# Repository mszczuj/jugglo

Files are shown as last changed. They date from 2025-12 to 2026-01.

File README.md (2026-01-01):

# Jugglo

This is a hobby IMU-based juggling ball project that streams inertial data over IP/UDP to a computer for visualization and sonification. 

Wi-Fi credentials live in `src/wifi_secret.h` (see below).

### 3d files 

3d files in stl (ball and electronics enclosure) for printing are in folder 3dfiles and were generated using cadquery

### Hardware

- Board: ESP32-C6 DevKitC-1
- IMU: BMI160 (I2C address 0x69)
- Wiring: SCL → GPIO20, SDA → GPIO19 (internal pull-ups enabled)

### Receiving data on the host
- Ensure the host machine is reachable at `MASTER_HOST` on `MASTER_PORT`.
- View raw sensor data and orientation filter output with:
```bash
> python read.py
14873,584,2,3996,-0.98681640625,-0.1142578125,0.056640625,0.244140625,0.0,0.1220703125,0,0,1767274563.513852
14873,584,2,3996,-0.986328125,-0.11376953125,0.05810546875,0.244140625,-0.06103515625,0.06103515625,1,0,1767274563.5138826
14873,584,2,3996,-0.98583984375,-0.11376953125,0.05908203125,0.244140625,-0.06103515625,0.06103515625,2,0,1767274563.5138955
...
```
Each row in console spam is csv formatted imu data with following columns:
```bash
timestamp_ms,device_sequence_number,sensor_id,battery_mv,accel_x,accel_y,accel_z,gyro_x,gyro_y,gyro_z,sequence_number,checksum_good,host_timestamp
```
acceleremter are in g and gyro in deg/s 

In order to see the basic visualisation see here: 
```bash 
> python read.py | python plot_raw_vis.py 
```

### Development 

The project is developed with PlatformIO on the Espressif platform (tested on Ubuntu; not yet on Windows).

#### TODO 
 - [ ] Easy Wi-Fi setup (without rebuilding the project / QR code or internal storage)
 - [ ] Recheck hardware design (external antenna and integrated IMU with microcontroller)
 - [ ] Pass the data to external VJ software

#### Configure secrets and target host

`src/wifi_secret.h` is git-ignored. Create it locally before building:
```c
#define WIFI_SSID "your-ssid"
#define WIFI_PASS "your-password"

// Host that receives UDP IMU packets
#define MASTER_HOST "host-or-ip"
#define MASTER_PORT 50555
```
M_H
> Note: `src/main.cpp` expects `MASTER_HOST`/`MASTER_PORT`; the default fallback defines `MASTER_*` but those macros are unused in the current code, so define the TCP_* values in your secret header.

## Build with PlatformIO
The repository also includes `platformio.ini`:
```bash
pio run -e esp32-c6-devkitc-1
pio run -e esp32-c6-devkitc-1 --target upload --upload-port /dev/ttyACM0
pio device monitor -e esp32-c6-devkitc-1
```

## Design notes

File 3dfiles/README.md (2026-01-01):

## 3d files for printing 

### TODO:
- [ ] redesign electronics enclosure  
make it more compact and put holder for button  
right now the antenna is put far away from battery to avoid communication problems (that may be possibly a overshoot)
- [ ] smaller ball 

### Ball

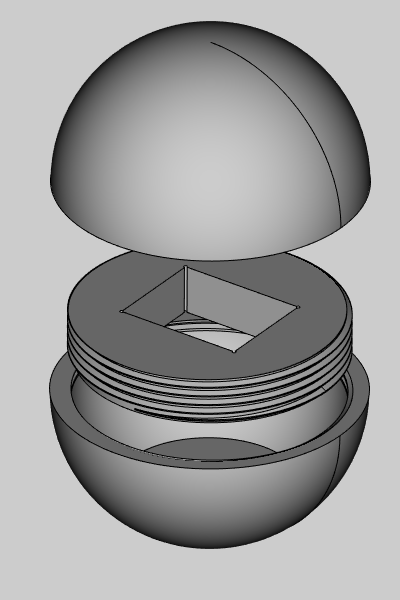
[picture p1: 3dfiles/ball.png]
Ball render


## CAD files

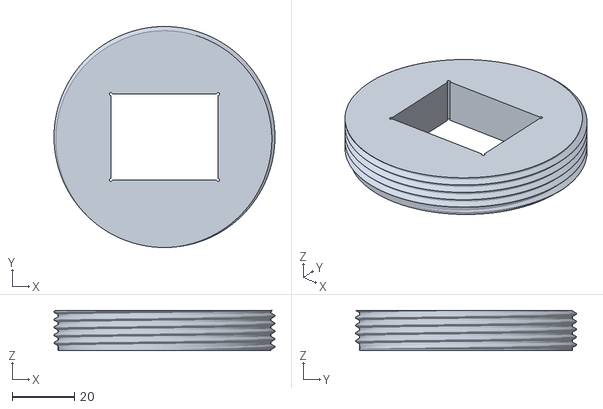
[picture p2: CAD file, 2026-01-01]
3dfiles/inner_thread.stl
71.2 x 71.2 x 13.0

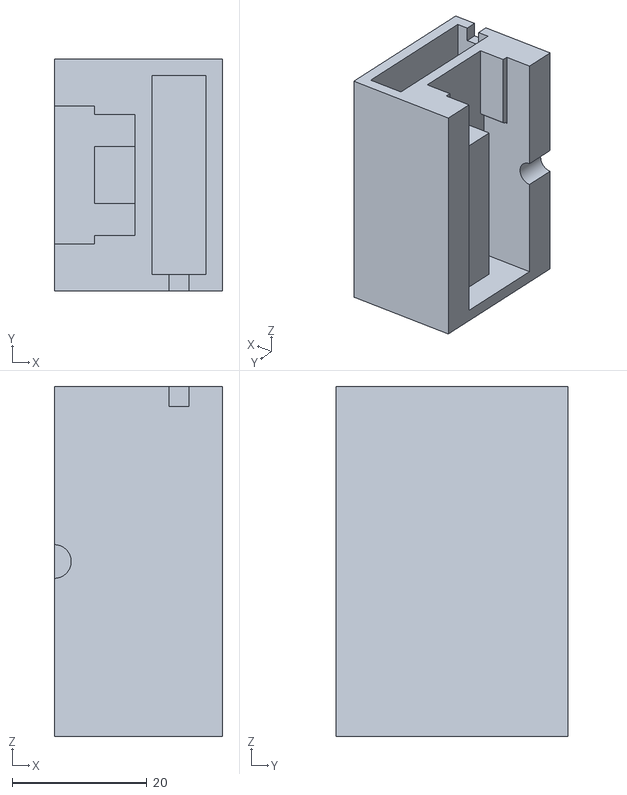
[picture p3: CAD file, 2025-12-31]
3dfiles/inner_box.stl
25.0 x 34.5 x 52.0

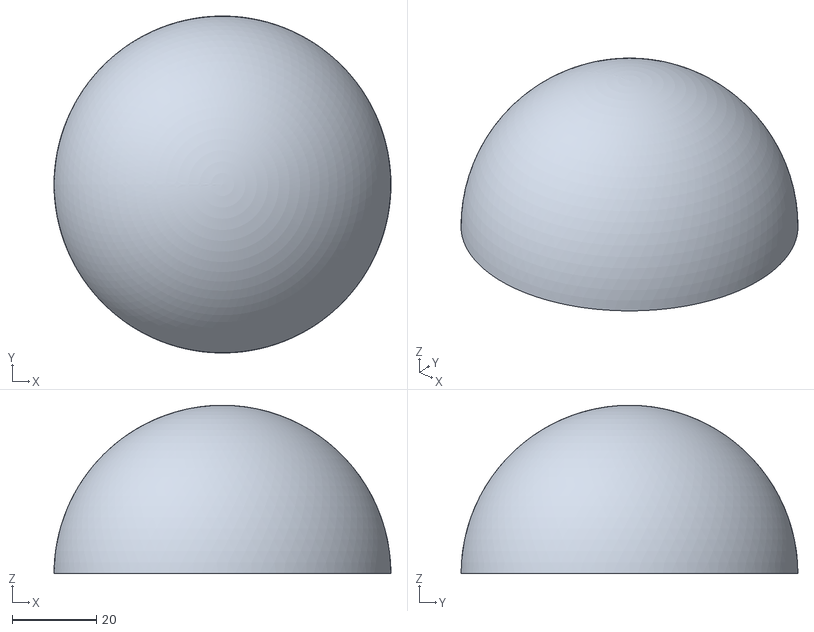
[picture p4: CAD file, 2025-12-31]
3dfiles/ball_lower.stl
80.0 x 80.0 x 40.0

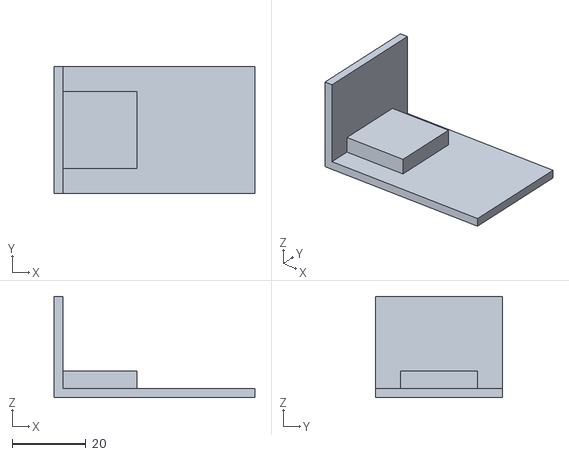
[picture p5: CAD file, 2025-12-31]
3dfiles/lid.stl
54.5 x 34.5 x 27.5

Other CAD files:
3dfiles/ball_upper.stl

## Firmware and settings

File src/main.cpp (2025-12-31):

#include "freertos/FreeRTOS.h"
#include "freertos/task.h"
#include "freertos/event_groups.h"
#include "driver/gpio.h"
#include "driver/i2c_master.h"
#include "esp_err.h"
#include "esp_log.h"
#include "esp_wifi.h"
#include "nvs_flash.h"
#include "esp_eap_client.h"
#include "esp_system.h"
#include "esp_netif.h"
#include "esp_event.h"
#include "driver/uart.h"
#include <netdb.h>
#include <cstdio>
#include <cerrno>
#include <cstring>
#include <sys/socket.h>
#include <unistd.h>

#include "battery.hpp"
#include "imu_bmi160.hpp"

#if __has_include("wifi_secret.h")
#include "wifi_secret.h"
#else
#warning "wifi_secret.h not found - using default WiFi credentials & master host/port"

#define WIFI_SSID "juglo_ap"
#define WIFI_PASS "jugl0mast4r"

#define MASTER_HOST "hostname.local"
#define MASTER_PORT 50555
#endif

#define I2C_SCL GPIO_NUM_20
#define I2C_SDA GPIO_NUM_19

#define I2C_FREQ_HZ 400000 // 400 kHz; higher speeds were flaky when WiFi traffic preempts I2C ISR
static i2c_master_bus_handle_t i2c_bus = nullptr;

#define DEFAULT_SCAN_LIST_SIZE 5

#define LED_GPIO GPIO_NUM_15   // ESP32-C6 DevKit LED

#define TAG "app"
#define BATTERY_ADC_UNIT     ADC_UNIT_1
#define BATTERY_ADC_CHANNEL  ADC_CHANNEL_0  // GPIO0 on ESP32-C6; change if your battery divider is on another pin
#define BATTERY_ADC_ATTEN    ADC_ATTEN_DB_11
#define BATTERY_DIVIDER_RATIO 2.0f          // scale ADC pin voltage back to battery voltage

static BatteryMonitor s_battery(BATTERY_ADC_UNIT, BATTERY_ADC_CHANNEL, BATTERY_ADC_ATTEN, BATTERY_DIVIDER_RATIO);

static void init_i2c(void)
{
    i2c_master_bus_config_t bus_cfg = {
        .i2c_port = I2C_NUM_0,
        .sda_io_num = I2C_SDA,
        .scl_io_num = I2C_SCL,
        .clk_source = I2C_CLK_SRC_DEFAULT,
        .glitch_ignore_cnt = 7,
        .intr_priority = 0,
        .trans_queue_depth = 0,
        .flags = {
            .enable_internal_pullup = true,
            .allow_pd = false,
        },
    };

    ESP_ERROR_CHECK(i2c_new_master_bus(&bus_cfg, &i2c_bus));
    ESP_LOGI(IMUTAG, "I2C bus ready on SDA=%d SCL=%d @ %d Hz", I2C_SDA, I2C_SCL, I2C_FREQ_HZ);
}


static EventGroupHandle_t s_wifi_event_group;
#define WIFI_CONNECTED_BIT BIT0
#define WIFI_FAIL_BIT      BIT1
static int s_retry_num = 0;
#define WIFI_MAX_RETRY 10

static void wifi_event_handler(void *arg,
                               esp_event_base_t event_base,
                               int32_t event_id,
                               void *event_data)
{
    if (event_base == WIFI_EVENT && event_id == WIFI_EVENT_STA_START) {
        esp_wifi_connect();
    } else if (event_base == WIFI_EVENT && event_id == WIFI_EVENT_STA_DISCONNECTED) {
        if (s_retry_num < WIFI_MAX_RETRY) {
            s_retry_num++;
            esp_wifi_connect();
        } else {
            xEventGroupSetBits(s_wifi_event_group, WIFI_FAIL_BIT);
        }
    } else if (event_base == IP_EVENT && event_id == IP_EVENT_STA_GOT_IP) {
        ip_event_got_ip_t *event = (ip_event_got_ip_t *)event_data;
        ESP_LOGI(TAG, "Got IP: " IPSTR, IP2STR(&event->ip_info.ip));
        s_retry_num = 0;
        xEventGroupSetBits(s_wifi_event_group, WIFI_CONNECTED_BIT);
    }
}

static void wifi_init_sta(void)
{
    s_wifi_event_group = xEventGroupCreate();

    ESP_ERROR_CHECK(esp_netif_init());
    ESP_ERROR_CHECK(esp_event_loop_create_default());
    esp_netif_create_default_wifi_sta();

    wifi_init_config_t cfg = WIFI_INIT_CONFIG_DEFAULT();
    ESP_ERROR_CHECK(esp_wifi_init(&cfg));

    ESP_ERROR_CHECK(esp_event_handler_instance_register(WIFI_EVENT,
                                                        ESP_EVENT_ANY_ID,
                                                        &wifi_event_handler,
                                                        NULL,
                                                        NULL));
    ESP_ERROR_CHECK(esp_event_handler_instance_register(IP_EVENT,
                                                        IP_EVENT_STA_GOT_IP,
                                                        &wifi_event_handler,
                                                        NULL,
                                                        NULL));

    wifi_config_t wifi_config = { 0 };
    strncpy((char*)wifi_config.sta.ssid, WIFI_SSID, sizeof(wifi_config.sta.ssid));
    strncpy((char*)wifi_config.sta.password, WIFI_PASS, sizeof(wifi_config.sta.password));

    // WPA2-PSK: ustaw minimalny poziom auth; dla typowego WPA2/WPA3-mixed działa bez certyfikatów
    wifi_config.sta.threshold.authmode = WIFI_AUTH_WPA2_PSK;

    ESP_ERROR_CHECK(esp_wifi_set_mode(WIFI_MODE_STA));
    ESP_ERROR_CHECK(esp_wifi_set_config(WIFI_IF_STA, &wifi_config));
    ESP_ERROR_CHECK(esp_wifi_start());

    EventBits_t bits = xEventGroupWaitBits(s_wifi_event_group,
                                          WIFI_CONNECTED_BIT | WIFI_FAIL_BIT,
                                          pdFALSE,
                                          pdFALSE,
                                          portMAX_DELAY);

    if (bits & WIFI_CONNECTED_BIT) {
        ESP_LOGI(TAG, "Connected to AP: %s", WIFI_SSID);
    } else {
        ESP_LOGE(TAG, "Failed to connect to AP: %s", WIFI_SSID);
    }
}


int sock = -1;

static void udp_client_connect(void)
{
    struct addrinfo hints = {
        .ai_family = AF_INET,
        .ai_socktype = SOCK_DGRAM,
    };
    struct addrinfo *res;

    char port_str[6];
    snprintf(port_str, sizeof(port_str), "%d", MASTER_PORT);

    int err = getaddrinfo(MASTER_HOST, port_str, &hints, &res);
    if (err != 0 || res == NULL) {
        ESP_LOGE(TAG, "DNS lookup failed: %d", err);
        return;
    }

    sock = socket(res->ai_family, res->ai_socktype, res->ai_protocol);
    if (sock < 0) {
        ESP_LOGE(TAG, "Unable to create UDP socket: errno %d", errno);
        freeaddrinfo(res);
        return;
    }

    // For UDP, no connect() is strictly needed, but you can use connect() to set default peer address
    if (connect(sock, res->ai_addr, res->ai_addrlen) != 0) {
        ESP_LOGE(TAG, "UDP socket connect failed: errno %d", errno);
        close(sock);
        freeaddrinfo(res);
        return;
    }

    ESP_LOGI(TAG, "UDP socket ready to %s:%d", MASTER_HOST, MASTER_PORT);

    freeaddrinfo(res);
}

void send_datagram(const void* data, size_t len) {
    if (sock < 0) {
        ESP_LOGW(TAG, "Socket not connected, cannot send data");
        return;
    }

    ssize_t bytes_sent = send(sock, data, len, MSG_DONTWAIT);
    if (bytes_sent < 0) {
        ESP_LOGE(TAG, "Failed to send data: errno %d", errno);
    } else if ((size_t)bytes_sent < len) {
        ESP_LOGW(TAG, "Partial data sent: %d of %d bytes", bytes_sent, len);
    }
}

struct __attribute__((packed)) ImuPayload{
    int16_t accel_gyro[6]; // 0-2: accel x,y,z; 3-5: gyro x,y,z
};

struct __attribute__((packed)) ImuDatagram {
    char magic[4]; // "IMUD"
    uint32_t timestamp_ms;     //  
    uint16_t sequence_number;  // 
    uint8_t  sensor_id;        // 
    uint16_t checksum;         // 16-bit ones' complement over all preceding bytes
    uint8_t  payload_size;     // size of payload in samples count
    uint16_t battery_mv;     // battery voltage in millivolts
    ImuPayload payload[10];        // payload data
};


static inline uint16_t imu_checksum16(const void *data, size_t len)
{
    const uint8_t *p = (const uint8_t *)data;
    uint32_t sum = 0;

    while (len >= 2) {
        uint16_t word = (uint16_t)((p[0] << 8) | p[1]);
        sum += word;
        p += 2;
        len -= 2;
    }

    if (len == 1) {
        uint16_t word = (uint16_t)(p[0] << 8);
        sum += word;
    }

    while (sum >> 16) {
        sum = (sum & 0xFFFFu) + (sum >> 16);
    }

    return (uint16_t)(~sum & 0xFFFFu);
}

static inline void imu_datagram_update_checksum(ImuDatagram& d) {
    d.checksum = 0;
    d.checksum = imu_checksum16(&(d.timestamp_ms), sizeof(ImuDatagram) - sizeof(d.magic) - sizeof(d.checksum));
}

static inline bool imu_datagram_verify(const ImuDatagram& d) {
    return d.checksum == imu_checksum16(&(d.timestamp_ms), sizeof(ImuDatagram) - sizeof(d.magic) - sizeof(d.checksum));
}

extern "C" void app_main(void)
{
    esp_err_t ret = nvs_flash_init();
    if (ret == ESP_ERR_NVS_NO_FREE_PAGES || ret == ESP_ERR_NVS_NEW_VERSION_FOUND) {
        ESP_ERROR_CHECK(nvs_flash_erase());
        ESP_ERROR_CHECK(nvs_flash_init());
    }

    vTaskDelay(pdMS_TO_TICKS(1000));
    ESP_LOGI(TAG, "Serial connection established");

    init_i2c();
    IMUBMI160 imu;

    ESP_ERROR_CHECK( imu.initialize(i2c_bus) );
    ESP_ERROR_CHECK( s_battery.init() );

    gpio_set_direction(LED_GPIO, GPIO_MODE_OUTPUT);
    gpio_set_level(LED_GPIO, 1);  // LED ON

    wifi_init_sta();    
    udp_client_connect();

    ImuDatagram datagram = {
        {'I', 'M', 'U', 'D'}, // magic 
        0,                    // timestamp_ms
        0,                    // sequence_number
        2,                    // sensor_id
        0,                    // checksum
        10,                   // payload_size        
        {}
    }; 


    int16_t accel_gyro_buf[6];
    size_t batch_size = 10;    
    uint16_t seq_num = 0;
    uint16_t battery_mv = 0;


    while (1) {

        vTaskDelay(pdMS_TO_TICKS(20)); // that gives imu time to fill fifo (with 8-9 samples), while we  wifi driver is sending data
        int samples_count = imu.update();
        datagram.timestamp_ms = (uint32_t)(esp_timer_get_time() / 1000);
        datagram.sequence_number = seq_num++;
        datagram.payload_size = samples_count;
        datagram.battery_mv = battery_mv;

        for (uint8_t sample_no=0; sample_no < samples_count && sample_no < batch_size; sample_no++) {
            // copy imu data to datagram
            memcpy((void*)datagram.payload[sample_no].accel_gyro, (const void*)&imu.imu_buffer[sample_no * 6], sizeof(accel_gyro_buf));
        
            // imu_datagram_update_checksum(datagram);
        }


        // variable size of dataram depending on samples count
        send_datagram(&datagram, sizeof(datagram) - (10 - samples_count) * sizeof(ImuPayload));

        // fwrite(&dgram_batch, sizeof(dgram_batch), samples_count, stdout);
        // fflush(stdout);

        static uint32_t last_batt_log_ms = 0;
        uint32_t now_ms = (uint32_t)(esp_timer_get_time() / 1000);
        if (now_ms - last_batt_log_ms > 10000) { // log battery roughly every 10 seconds
            battery_mv = s_battery.read_voltage_mv();
            if (battery_mv >= 0) {
                ESP_LOGI(TAG, "Battery: %d mV", battery_mv);
            } else {
                ESP_LOGW(TAG, "Battery voltage read failed");
            }
            last_batt_log_ms = now_ms;
        }
                    
    }
}

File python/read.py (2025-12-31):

#%%
from dataclasses import dataclass
from typing import Generator
import serial
import struct
import argparse
import socket
import time
import matplotlib.pyplot as plt
from numpy_ringbuffer  import RingBuffer
import numpy as np

## this must match the definitions in imu_base.hpp and main.cpp
aRes = 16.0 / 32768.0    	# ares value for full range (16g) readings
gRes = 2000.0 / 32768.0	    # gres value for full range (2000dps) readings

# Python struct format string for ImuDatagram (without magic header)
# Format: I (timestamp_ms) + H (sequence_number) + B (sensor_id) + H * (checksum) + B (payload_size) + H(battery_mv)
IMUD_FORMAT_HDR = '<IHBHBH' 
IMUD_HDR_SIZE = struct.calcsize(IMUD_FORMAT_HDR)

@dataclass
class ImuMeasurement:
    timestamp_ms: int
    sequence_number: int
    sensor_id: int
    accel_gyro: tuple
    device_sequence_number: int
    battery_mv: int
    checksum_good: bool     
    host_timestamp: float 

    def to_string(self) -> str:
        """String representation of the ImuMeasurement."""
        return (f"ImuMeasurement(timestamp_ms={self.timestamp_ms}, "
                f"device_sequence_number={self.device_sequence_number}, "
                f"sensor_id={self.sensor_id}, "
                f"battery_mv={self.battery_mv}, "
                f"accel_gyro={self.accel_gyro}, "
                f"sequence_number={self.sequence_number}, "
                f"checksum_good={self.checksum_good}, "
                f"host_timestamp={self.host_timestamp})")
    
    def to_csv_row(self) -> str:
        """CSV row representation of the ImuMeasurement."""
        return (f"{self.timestamp_ms},{self.device_sequence_number},"
                f"{self.sensor_id},{self.battery_mv},"
                f"{','.join(map(str, self.accel_gyro))},"
                f"{self.sequence_number},{int(self.checksum_good)},"
                f"{self.host_timestamp}")
    
    @classmethod
    def from_csv_row(cls, row: str):
        """Create an ImuMeasurement from a CSV row."""
        parts = row.strip().split(',')
        return cls(
            timestamp_ms=int(parts[0]),
            device_sequence_number=int(parts[1]),
            sensor_id=int(parts[2]),
            battery_mv=int(parts[3]),
            accel_gyro=tuple(map(float, parts[4:10])),
            sequence_number=int(parts[10]),
            checksum_good=bool(int(parts[11])),
            host_timestamp=float(parts[12])
        )   


def imu_checksum16(data) -> int:
    """
    Internet checksum (RFC 1071).
    Returns a 16-bit integer (0..65535).
    """
    if not isinstance(data, (bytes, bytearray, memoryview)):
        raise TypeError("data must be bytes-like")

    b = bytes(data)
    if len(b) % 2 == 1:
        b += b"\x00"  # pad odd length with one zero byte

    s = 0
    for i in range(0, len(b), 2):
        word = (b[i] << 8) + b[i + 1]
        s += word

    # fold carries
    s = (s & 0xFFFF) + (s >> 16)
    s = (s & 0xFFFF) + (s >> 16)  # in case another carry was created

    return (~s) & 0xFFFF


def parse_imu_datagram(data) -> Generator[ImuMeasurement, None, None]:
    timestamp_ms, sequence_number, sensor_id, checksum, payload_size, battery_mv = struct.unpack(IMUD_FORMAT_HDR, data[4:IMUD_HDR_SIZE  + 4])
    assert payload_size <=10, "Payload size exceeds maximum samples count"
    accel_gyro = struct.unpack('<' + 'h' * payload_size * 6, data[IMUD_HDR_SIZE  + 4:IMUD_HDR_SIZE  + 4 + payload_size * 12])    
    for i in range(payload_size):
        start_idx = i * 6
        sample_accel_gyro = (
            accel_gyro[start_idx + 3] * aRes,
            accel_gyro[start_idx + 4] * aRes,
            accel_gyro[start_idx + 5] * aRes,
            accel_gyro[start_idx + 0] * gRes,
            accel_gyro[start_idx + 1] * gRes,
            accel_gyro[start_idx + 2] * gRes,
        )
        checksum_good = checksum == imu_checksum16(data[:-2])
        yield ImuMeasurement(
            timestamp_ms=timestamp_ms,
            device_sequence_number=sequence_number,
            sequence_number = parse_imu_datagram.local_sequence_number,
            sensor_id=sensor_id,            
            checksum_good=checksum_good,
            battery_mv=battery_mv,
            accel_gyro=sample_accel_gyro,
            host_timestamp=time.time()
        )
        parse_imu_datagram.local_sequence_number += 1
    
parse_imu_datagram.local_sequence_number = 0

def read_datagram_from_serial(port, baudrate=115_200, timeout=1):    
    with serial.Serial(port, baudrate=baudrate, timeout=timeout) as ser:
        header = b'IMUD'
        buffer = bytearray()
        while True:
            while True: # find header
                byte = ser.read(1)
                # this is just ot check visually on terminal if we parse it properly
                # print ('.', end='', flush=True)
                if byte:
                    buffer.append(byte[0])
                    if len(buffer) > len(header):
                        buffer.pop(0)
                    if bytes(buffer) == header:                    
                        buffer.clear()
                        break            
                
            # rest of the datagram
            datagram = ser.read(IMUD_SIZE)
            if len(datagram) == IMUD_SIZE:  
                imu_data = parse_imu_datagram(datagram)
                yield imu_data


def read_datagram_from_socket(host, port, timeout=1.0) -> Generator[ImuMeasurement, None, None]:
    """Generator that binds a UDP socket and yields parsed datagrams from clients."""
    header = b'IMUD'
    header_len = len(header) # 4 bytes

    with socket.socket(socket.AF_INET, socket.SOCK_DGRAM) as server:
        server.setsockopt(socket.SOL_SOCKET, socket.SO_REUSEADDR, 1)
        server.bind((host, port))
        server.settimeout(timeout)
        # print('UDP server listening on {}:{}'.format(host, port))

        while True:
            try:
                #read max size of the packet (magic + header + max payload)
                # TODO add additinoal check for checksum and sequence number order (if UDP packets are lost or out of order)
                data, addr = server.recvfrom(IMUD_HDR_SIZE + 4 + 6*2*10)  # read a packet; 4 bytes for magic ('IMUD')
                for m in parse_imu_datagram(data):
                    yield m                
            except socket.timeout:
                continue
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

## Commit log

2025-12-31 Add battery monitoring functionality with ADC integration
    - Implement BatteryMonitor class for reading battery voltage
    - Update main application to initialize and log battery voltage
    - Modify IMU datagram structure to include battery voltage
    - Refactor IMU data handling to accommodate new battery data
2025-12-31 Add browse recording and camera functionality with IMU data handling
2026-01-01 small fix in 3d print and readme
    [inner_thread.stl, outer_thread.stl]
